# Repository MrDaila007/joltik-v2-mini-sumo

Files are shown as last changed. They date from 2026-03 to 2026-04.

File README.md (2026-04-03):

# Joltik V2 — Mini Sumo Robot



Mini sumo competition robot — from SolidWorks CAD to firmware for three hardware platforms. Includes Arduino sketches for ATmega328 (V1) and RP2040-Zero (V2), a Zephyr RTOS port, and a WiFi web-controller on ESP8266.

## Hardware

| | V1 Board | V2 Board |
|---|---|---|
| **MCU** | ATmega328 (Arduino Nano) | RP2040-Zero |
| **Opponent sensors** | 3x SharpIR analog + 2x digital | 4x digital (active-low) |
| **Edge sensors** | 1x analog | 2x analog |
| **Motor driver** | TA6586 dual H-bridge | TA6586 dual H-bridge |
| **Extras** | — | WS2812 LED, RC5 IR remote, servo, OLED (opt.) |
| **WiFi control** | — | ESP8266 (Wemos D1 Mini) companion |

## Repository Structure

```
CAD/
  ├── *.SLDASM / *.SLDPRT      SolidWorks assemblies & parts
  ├── CUT/                      DXF files for laser/CNC cutting
  ├── STEP/                     STEP exports for cross-CAD use
  └── STL/                      3D-printable models
FIRMWARE/
  ├── JoltikV1_last_test_firmware/   Competition firmware (ATmega328)
  ├── JoltikV2_sumo_firmware/        Competition firmware (RP2040-Zero)
  ├── JoltikV2_test_firmware/        Extended test with ESP telemetry link
  ├── Joltik_v2_sumo_board_test/     Hardware verification sketch (V2)
  ├── JoltikV2_web_controller/       WiFi dashboard (ESP8266)
  ├── joltik_v2_zephyr/              Zephyr RTOS firmware (RP2040-Zero)
  └── Lib/                           Vendored: NeoPixel, GyverMotor, RC5, SharpIR
.github/workflows/ci.yml            Arduino + Zephyr build CI
```

## Build & Upload

### Arduino (arduino-cli)

```bash
# V1 — Arduino Nano
arduino-cli compile --fqbn arduino:avr:nano --libraries FIRMWARE/Lib \
  FIRMWARE/JoltikV1_last_test_firmware/
arduino-cli upload  --fqbn arduino:avr:nano -p /dev/ttyUSB0 \
  FIRMWARE/JoltikV1_last_test_firmware/

# V2 — RP2040-Zero
arduino-cli compile --fqbn rp2040:rp2040:waveshare_rp2040_zero --libraries FIRMWARE/Lib \
  FIRMWARE/JoltikV2_sumo_firmware/
arduino-cli upload  --fqbn rp2040:rp2040:waveshare_rp2040_zero -p /dev/ttyACM0 \
  FIRMWARE/JoltikV2_sumo_firmware/

# Web controller — ESP8266 (Wemos D1 Mini)
arduino-cli compile --fqbn esp8266:esp8266:d1_mini --libraries FIRMWARE/Lib \
  FIRMWARE/JoltikV2_web_controller/
```

Libraries in `FIRMWARE/Lib/` must be accessible to the build system — pass `--libraries FIRMWARE/Lib` or copy/symlink into your Arduino libraries folder.

### Zephyr RTOS

```bash
cd FIRMWARE/joltik_v2_zephyr
west build -b rp2040_zero -p always
west flash          # or copy build/zephyr/zephyr.uf2 to the RP2040 in bootloader mode
```

## V2 Competition Firmware

- **State machine**: search (spin) -> attack (track & ram) -> backoff (on edge)
- **4 start tactics**: straight charge, reverse start, left sweep, right sweep
- **WS2812 LED status**: white = waiting, green = searching, blue = attacking, red = edge
- **Button**: single click = start/stop, double click = cycle tactics
- **IR remote** (RC5): tactic selection and start/stop (processed on RP2040 second core)
- **Servo**: pin 9, plow deployment
- **Optional OLED**: `#define USE_DISPLAY` — sensor states, tactic, IR commands
- **Serial debug**: `#define DEBUG_ENABLE` (115200 baud)

## Zephyr Firmware

Modular rewrite of the V2 competition firmware on Zephyr RTOS:

- Multi-threaded: IR decoding thread + main combat loop
- Persistent settings via NVS (flash storage)
- USB CDC-ACM console with shell commands for debug
- Zephyr logging subsystem
- Same state machine and tactics as the Arduino version

## Web Controller (ESP8266)

WiFi dashboard for the V2 robot via a companion Wemos D1 Mini:

- **AP**: SSID `Joltik-V2`, password `joltik2024`, accessible at `http://joltik.local`
- **WebSocket**: real-time sensor telemetry and motor control
- **Dashboard**: live robot visualization, motor sliders, D-pad, line sensor graphs, config panel, debug log
- **Serial link**: 9600 baud to RP2040-Zero (TX/RX on D5/D6)

## Pin Mapping (V2)

| Function | Pin |
|---|---|
| Motor A | GPIO 5, 6 |
| Motor B | GPIO 7, 8 |
| Opponent FL / FR | GPIO 12, 13 |
| Opponent L / R | GPIO 10, 11 |
| Line L / R | A3, A2 |
| Servo | GPIO 9 |
| Button | GPIO 15 |
| IR Receiver | GPIO 14 |
| WS2812 LED | GPIO 16 |
| OLED SDA / SCL | GPIO 2, 3 |

## License

[Apache 2.0](LICENSE) — 2026 Danila Surok

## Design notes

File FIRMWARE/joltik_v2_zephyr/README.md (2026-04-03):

# Joltik V2 Zephyr Firmware

Zephyr RTOS firmware for the Joltik V2 mini sumo robot on RP2040-Zero.

Modular rewrite of the Arduino competition firmware with multi-threading, persistent settings (NVS), interactive shell over USB, and a full unit test suite.

## Quick Start

```bash
# Build
make

# Flash (hold BOOTSEL, plug USB, release)
make flash

# Serial console (shell + logs)
make monitor

# Build with OLED display support
make display
```

## Features

- **Combat state machine** — search / attack / backoff with 4 configurable start tactics
- **4 opponent sensors** (IR, active-low) + **2 line sensors** (ADC)
- **WS2812 LED** — color-coded robot state
- **RC5 IR remote** — tactic selection and start/stop (dedicated thread)
- **Servo** — plow deployment (0-180 degrees)
- **Button** — single click start/stop, double click cycle tactics
- **Persistent settings** — speeds, tactic, line threshold saved to flash (NVS)
- **USB shell** — live sensor readout, motor test, config tuning (115200 baud)
- **Optional OLED** — SSD1306 128x32 via I2C (`CONFIG_JOLTIK_DISPLAY=y`)
- **Unit tests** — 7 test suites on native_sim

## Build Requirements

- Zephyr SDK 0.17+ with ARM toolchain
- West workspace with Zephyr v4.3
- Python venv with west, pyelftools

Paths are configured in `Makefile` — adjust `ZEPHYR_BASE`, `ZEPHYR_SDK`, and `VENV` to match your setup.

## Make Targets

| Target | Description |
|---|---|
| `make` / `make build` | Build firmware |
| `make flash` | Copy UF2 to RP2040 in bootloader mode |
| `make monitor` | Open USB serial console |
| `make flash-monitor` | Flash then monitor |
| `make display` | Build with OLED enabled |
| `make test` | Build and run unit tests |
| `make size` | Show firmware size |
| `make rom_report` / `make ram_report` | Memory usage |
| `make menuconfig` | Interactive Kconfig |
| `make clean` / `make pristine` | Clean build |

## Project Structure

```
├── CMakeLists.txt
├── Kconfig                     # Optional features (display, IR)
├── prj.conf                    # Zephyr kernel config
├── Makefile                    # Build shortcuts
├── boards/
│   └── rp2040_zero.overlay     # Pin mappings (devicetree)
├── src/
│   ├── main.c                  # State machine & main loop
│   ├── motors.c/h              # PWM motor control
│   ├── sensors.c/h             # Opponent (GPIO) + line (ADC) sensors
│   ├── combat.c/h              # Attack / backoff / search logic
│   ├── tactics.c/h             # 4 start routines
│   ├── led.c/h                 # WS2812 state colors
│   ├── servo.c/h               # Servo angle control
│   ├── button.c/h              # Debounced single/double click
│   ├── rc5.c/h                 # RC5 IR protocol decoder
│   ├── settings.c/h            # NVS persistent storage
│   ├── shell_cmds.c            # Shell command handlers
│   └── display.c/h             # Optional SSD1306 OLED
└── tests/                      # ztest unit tests (native_sim)
```

## Documentation

- [Architecture](docs/architecture.md) — modules, threads, state machine
- [Pin Mapping](docs/pinout.md) — GPIO, PWM, ADC assignments
- [Shell Commands](docs/shell.md) — interactive debug interface
- [Settings](docs/settings.md) — persistent configuration via NVS
- [Testing](docs/testing.md) — unit tests and how to run them

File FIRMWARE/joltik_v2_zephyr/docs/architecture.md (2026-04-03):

# Architecture

## Modules

```
main.c ─────── State machine, init, main loop
  ├── motors     PWM drive control (-255..255)
  ├── sensors    4x opponent GPIO + 2x line ADC
  ├── combat     attack() / backoff() / search()
  ├── tactics    4 start routines
  ├── led        WS2812 color by state
  ├── servo      Plow angle (0-180)
  ├── button     Single/double click detection
  ├── rc5        RC5 IR decoder (separate thread)
  ├── settings   NVS flash persistence
  ├── shell_cmds Debug commands over USB
  └── display    Optional SSD1306 OLED
```

## Threads

| Thread | Stack | Priority | Role |
|---|---|---|---|
| **main** | 4096 B | 0 (preemptive) | State machine, combat loop |
| **ir_thread** | 1024 B | 5 (cooperative) | RC5 message dispatch (tactic select / power toggle) |
| **system workqueue** | 2048 B | — | Deferred LED updates, display refresh |

## State Machine

```
                 ┌──────────┐
        power on │ WAITING  │ LED: white
                 │ (idle)   │ Button/IR/start_pin triggers start
                 └────┬─────┘
                      │ start event
                 ┌────▼─────┐
                 │COUNTDOWN │ LED: green, 5 sec (1s per count)
                 └────┬─────┘
                      │
                 ┌────▼─────┐
                 │ TACTIC   │ LED: yellow, executes selected tactic (0-3)
                 └────┬─────┘
                      │
              ┌───────▼────────┐
              │  COMBAT LOOP   │
              │                │
              │  ┌──────────┐  │
          no  │  │ SEARCH   │  │ LED: green
       opponent  │ (spin)   │  │ Rotate in searchDir
              │  └─────┬────┘  │
              │   opponent     │
              │   detected     │
              │  ┌─────▼────┐  │
              │  │ ATTACK   │  │ LED: blue
              │  │ (track)  │  │ Priority-based targeting
              │  └─────┬────┘  │
              │   edge         │
              │   detected     │
              │  ┌─────▼────┐  │
              │  │ BACKOFF  │  │ LED: red
              │  │ (escape) │  │ Reverse → rotate → forward
              │  └──────────┘  │
              └───────┬────────┘
                      │ button press
                 ┌────▼─────┐
                 │ WAITING  │ motors stop
                 └──────────┘
```

## Attack Priority

When opponent is detected, `attack()` checks sensors in this order:

1. **All 4 sensors** — full ram at `max_speed` + ramp counter (accelerating)
2. **Both front** (FL + FR) — straight at `attack_speed`
3. **Front-left** — slight left turn
4. **Front-right** — slight right turn
5. **Side-left only** — tank rotate left (200ms timeout)
6. **Side-right only** — tank rotate right (200ms timeout)

## Start Tactics

| ID | Name | Behavior |
|---|---|---|
| 0 | Straight charge | Forward 150ms, then search for 200ms |
| 1 | Reverse start | Reverse 400ms, rotate 150ms, then tactic 0 |
| 2 | Left sweep | Rotate left 300ms, then tactic 0 |
| 3 | Right sweep | Rotate right 300ms, then tactic 0 |

## Edge Detection

Line sensors (ADC) are checked every loop iteration:
- `line_read_left()` / `line_read_right()` return 12-bit ADC values (0-4095)
- Value **above** threshold = on ring (black surface)
- Value **at or below** threshold = ring edge (white line)
- Left edge detected → `backoff(DIR_RIGHT)`
- Right edge detected → `backoff(DIR_LEFT)`
- Default threshold: **2000** (configurable via shell or NVS)

## Motor Control

`drive(left, right)` accepts values from -255 to 255:
- Positive = forward, negative = reverse
- Direction pin set to 0 (forward) or 1 (reverse)
- PWM duty: `pulse = period * abs(speed) / 255`
- Both motors share 50Hz PWM (20ms period)

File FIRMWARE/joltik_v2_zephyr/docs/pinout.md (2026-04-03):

# Pin Mapping

RP2040-Zero pinout for the Joltik V2 sumo board. Defined in `boards/rp2040_zero.overlay`.

## GPIO Assignment

| Function | GPIO | Type | Notes |
|---|---|---|---|
| Motor L speed | 5 | PWM (slice 2B) | 50 Hz, duty 0-100% |
| Motor L direction | 6 | Output | 0 = forward, 1 = reverse |
| Motor R direction | 7 | Output | 0 = forward, 1 = reverse |
| Motor R speed | 8 | PWM (slice 4A) | 50 Hz, duty 0-100% |
| Servo | 9 | PWM (slice 4B) | 50 Hz, 500-2500 us pulse |
| Opponent side-left | 10 | Input, active-low | IR distance sensor |
| Opponent side-right | 11 | Input, active-low | IR distance sensor |
| Opponent front-left | 12 | Input, active-low | IR distance sensor |
| Opponent front-right | 13 | Input, active-low | IR distance sensor |
| IR receiver | 14 | Input, active-low | RC5 protocol |
| Button | 15 | Input, active-high | 50ms debounce |
| WS2812 LED | 16 | LED strip (PIO) | Single RGB pixel |
| Line sensor right | 28 (A2) | ADC channel 2 | 12-bit, 0-4095 |
| Line sensor left | 29 (A3) | ADC channel 3 | 12-bit, 0-4095 |

## PWM Notes

- GPIO 8 (motor R) and GPIO 9 (servo) share **PWM slice 4** — both run at 50 Hz
- GPIO 5 (motor L) uses **PWM slice 2**
- Motor PWM period: 20 ms (50 Hz)
- Servo pulse: 500 us (0 deg) to 2500 us (180 deg)

## USB

- CDC ACM UART on USB for shell console and logging (115200 baud)

## Flash Layout

| Region | Offset | Size | Purpose |
|---|---|---|---|
| Code | 0x100 | ~1984 KB | Application firmware |
| NVS storage | 0x1F0000 | 64 KB | Persistent settings |

## I2C (optional OLED)

Enabled with `CONFIG_JOLTIK_DISPLAY=y`:

| Function | GPIO |
|---|---|
| SDA | 2 |
| SCL | 3 |

Display: SSD1306 128x32, I2C address 0x3C.

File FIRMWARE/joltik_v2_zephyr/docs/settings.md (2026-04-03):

# Settings

Robot parameters are stored in flash via Zephyr NVS (Non-Volatile Storage) and persist across power cycles.

## Parameters

| Parameter | Default | Range | Description |
|---|---|---|---|
| `current_tactic` | 0 | 0-3 | Start tactic (straight / reverse / left / right) |
| `line_threshold` | 2000 | 0-4095 | ADC threshold for ring edge detection |
| `max_speed` | 200 | 0-255 | Ram speed when all sensors triggered |
| `straight_speed` | 125 | 0-255 | Forward speed after tactic |
| `search_speed` | 100 | 0-255 | Rotation speed while searching |
| `rotate_speed` | 125 | 0-255 | Rotation speed during attack tracking |
| `breakout_speed` | 160 | 0-255 | Reverse/escape speed on edge |
| `attack_speed` | 125 | 0-255 | Forward speed when opponent in front |

## NVS Keys

Settings are stored under the `joltik` namespace:

| Key | Type | Mapped to |
|---|---|---|
| `joltik/tactic` | uint8 | `current_tactic` |
| `joltik/threshold` | uint16 | `line_threshold` |
| `joltik/max_spd` | uint8 | `max_speed` |
| `joltik/str_spd` | uint8 | `straight_speed` |
| `joltik/srch_spd` | uint8 | `search_speed` |
| `joltik/rot_spd` | uint8 | `rotate_speed` |
| `joltik/brk_spd` | uint8 | `breakout_speed` |
| `joltik/atk_spd` | uint8 | `attack_speed` |

## Usage

### Via Shell

```
config show                    # view all
config threshold 1800          # change threshold
config speed max 220           # change max speed
config save                    # write to flash
```

Changes take effect immediately but are **not saved to flash** until `config save` is called.

### Via Code

```c
#include "settings.h"

// Global instance
extern struct robot_settings g_settings;

// Read
uint8_t spd = g_settings.max_speed;

// Modify
g_settings.max_speed = 220;

// Persist to flash
app_settings_save();
```

### Startup Flow

1. `app_settings_init()` called from `main()`
2. NVS subsystem initialized (`settings_subsys_init`)
3. Settings loaded from flash (`settings_load`)
4. Missing keys filled with defaults
5. `g_settings` ready for use

## Flash Storage

- Partition: 64 KB at offset `0x1F0000`
- Backend: Zephyr NVS
- Wear leveling handled by NVS internally
- Write protection disabled via `CONFIG_MPU_ALLOW_FLASH_WRITE=y`

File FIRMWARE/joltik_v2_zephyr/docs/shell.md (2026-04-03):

# Shell Commands

Interactive debug shell over USB CDC ACM (115200 baud). Connect with any serial terminal:

```bash
make monitor
# or
picocom /dev/ttyACM0 -b 115200
```

## Commands

### sensors

Read all sensor values.

```
uart:~$ sensors
Opponent: FL=1 FR=0 L=0 R=0
Line:     L=2850 R=3100  ring: L=yes R=yes
```

### motor drive / motor stop

Direct motor control for testing.

```
uart:~$ motor drive 100 100     # both forward at ~40% speed
uart:~$ motor drive -150 150    # tank rotate left
uart:~$ motor drive 0 0         # stop
uart:~$ motor stop              # same as drive 0 0
```

Values: -255 to 255 (clamped).

### tactic

Get or set the current start tactic.

```
uart:~$ tactic             # show current
Current tactic: 0
uart:~$ tactic 2           # set to left sweep
Tactic set to 2
```

Tactics: 0 = straight, 1 = reverse, 2 = left sweep, 3 = right sweep.

### config show

Display all settings.

```
uart:~$ config show
  tactic:    0
  threshold: 2000
  max_speed: 200
  straight:  125
  search:    100
  rotate:    125
  breakout:  160
  attack:    125
```

### config threshold

Set line sensor threshold (0-4095).

```
uart:~$ config threshold 1800
Line threshold set to 1800
```

Higher value = more sensitive to ring edge.

### config speed

Adjust motor speed parameters.

```
uart:~$ config speed max 220
uart:~$ config speed search 80
uart:~$ config speed attack 150
```

Valid names: `max`, `straight`, `search`, `rotate`, `breakout`, `attack`.
Valid values: 0-255.

### config save

Persist current settings to flash. They survive power cycles.

```
uart:~$ config save
Settings saved
```

### led

Set LED to a specific RGB color (for testing).

```
uart:~$ led 255 0 0        # red
uart:~$ led 0 255 0        # green
uart:~$ led 0 0 0          # off
```

### servo

Set servo angle (for testing).

```
uart:~$ servo 0             # fully retracted
uart:~$ servo 90            # center
uart:~$ servo 180           # fully extended
```

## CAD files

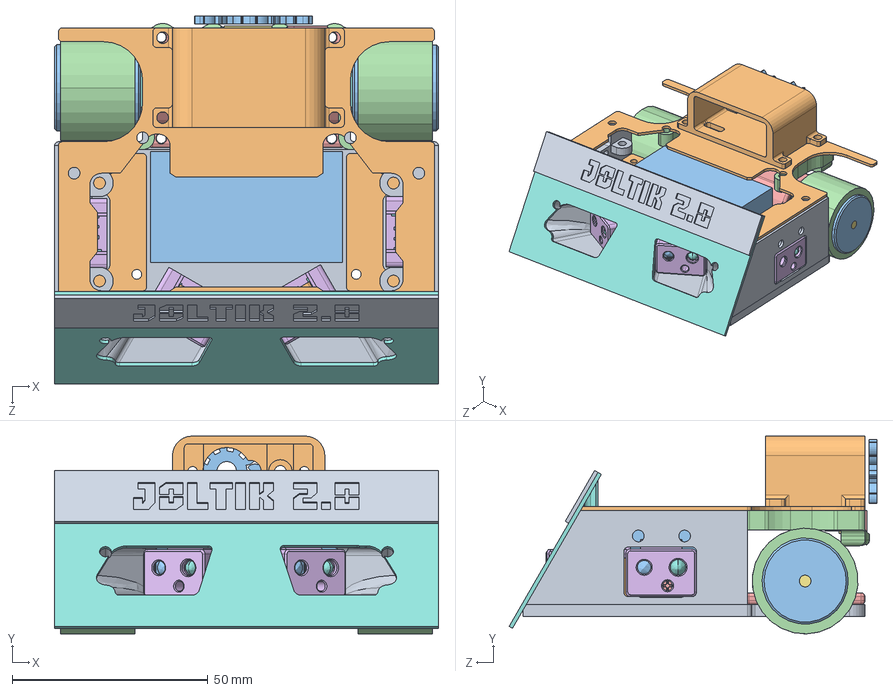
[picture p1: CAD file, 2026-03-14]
CAD/STEP/Joltik2.0 Assembly.STEP
98.0 x 50.5 x 93.8 mm
Base plate_По умолчанию
верхняя пластина_По умолчанию
Sumo_weel x 2
Tire_new_По умолчанию x 2
Motor bracket_По умолчанию x 2
Motor_По умолчанию x 2
Main_1_По умолчанию
Board.STEP x 4
1608.STEP x 40
LED-1608.STEP x 8
LED-5MM.STEP x 4
SOT-23.STEP x 4
SOIC-08N.STEP x 4
TSSP40_Right angle bend.STEP x 4
2012.STEP x 4
SMD-RS-VR.STEP x 4
MO Casing.STEP x 4
pololu-QTR-1a x 2
Front plate_По умолчанию
Side panel_По умолчанию x 2
weight boost_По умолчанию x 2
Battery
Charger_port_По умолчанию
XT30U-M
JST - XH - Thru (V) - 4Pin - 2.54mm
Part2^Joltik2.0 Assembly
Joltik_logo
Servo mount_По умолчанию
spur gear_iso_ISO - Spur gear 1.375M 10T 20PA 2FW ---S10A75H50L5.0N x 2

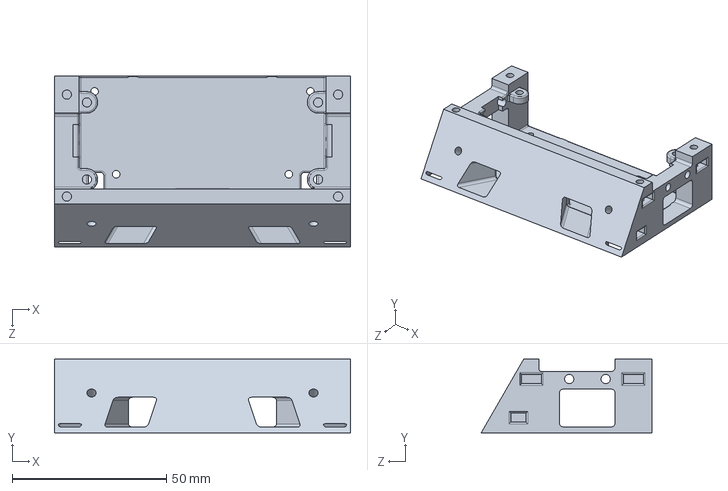
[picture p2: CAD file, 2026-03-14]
CAD/Main.SLDPRT
96.0 x 24.0 x 55.4 mm

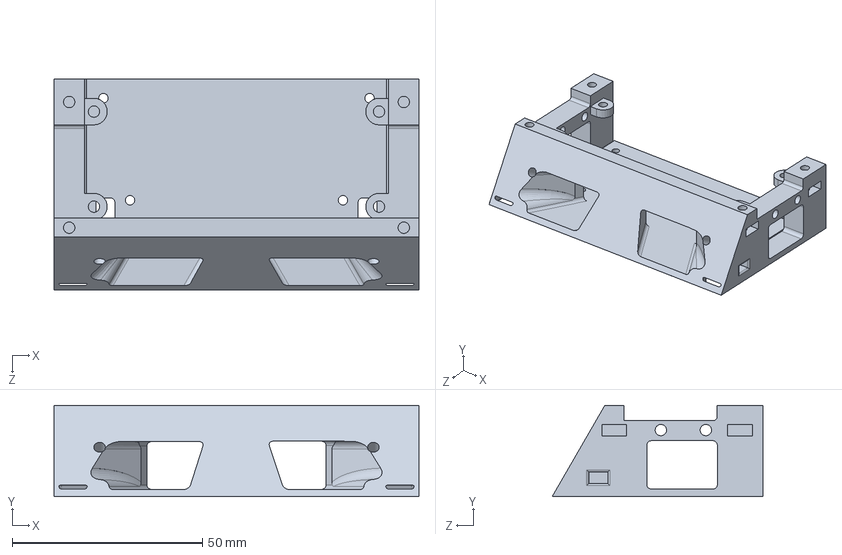
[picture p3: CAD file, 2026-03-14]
CAD/Main_1.SLDPRT
96.0 x 24.0 x 55.4 mm

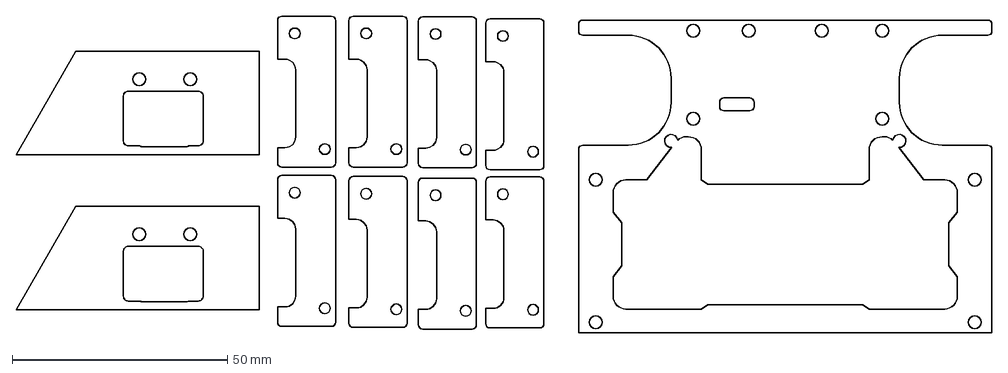
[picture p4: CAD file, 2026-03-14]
CAD/CUT/Side_weight_boost_top_panel_1mm.DXF
226.6 x 73.5 mm

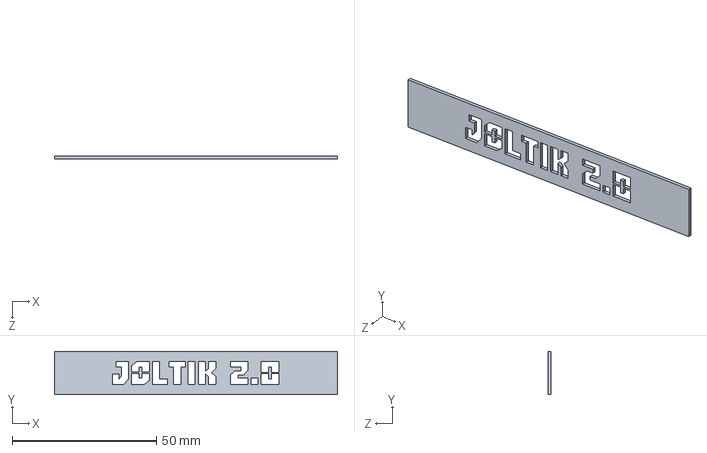
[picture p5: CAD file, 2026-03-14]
CAD/Joltik_logo.SLDPRT
98.0 x 15.0 x 1.00 mm

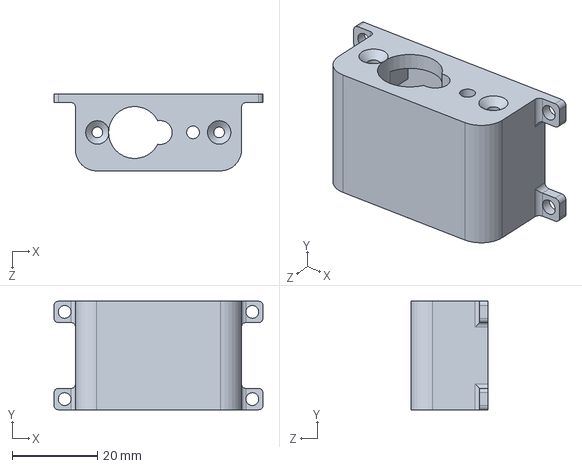
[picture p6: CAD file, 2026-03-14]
CAD/STL/Servo mount.SLDPRT
48.9 x 25.4 x 18.0 mm

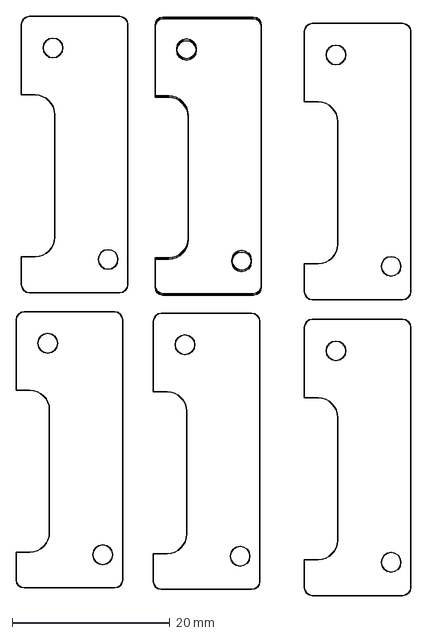
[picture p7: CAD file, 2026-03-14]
CAD/CUT/weight boostz_2mm.DXF
50.1 x 73.5 mm

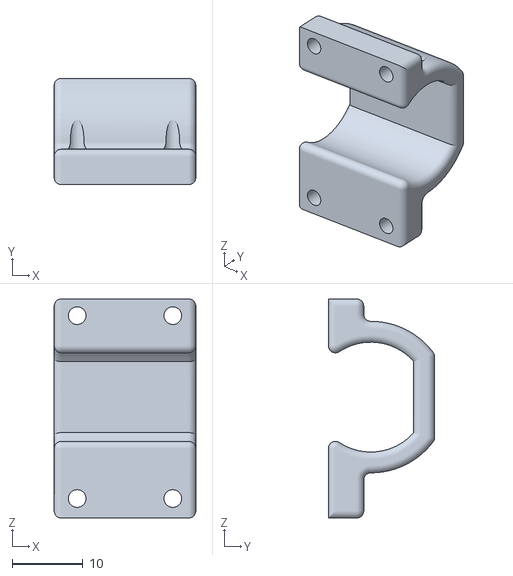
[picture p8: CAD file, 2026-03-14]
CAD/STL/Motor bracket_offset.STL
20.0 x 15.0 x 30.9

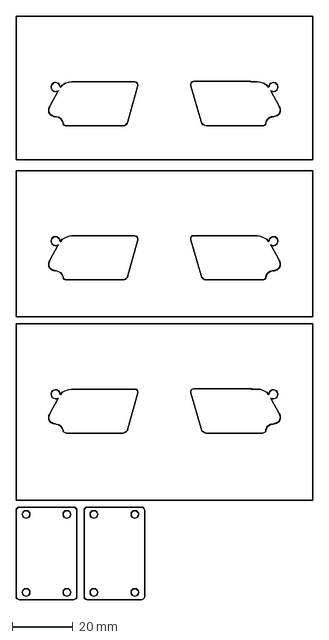
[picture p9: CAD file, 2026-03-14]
CAD/CUT/Front_plate_9-20mm_motor_spacer_1mm.DXF
98.0 x 192.8 mm

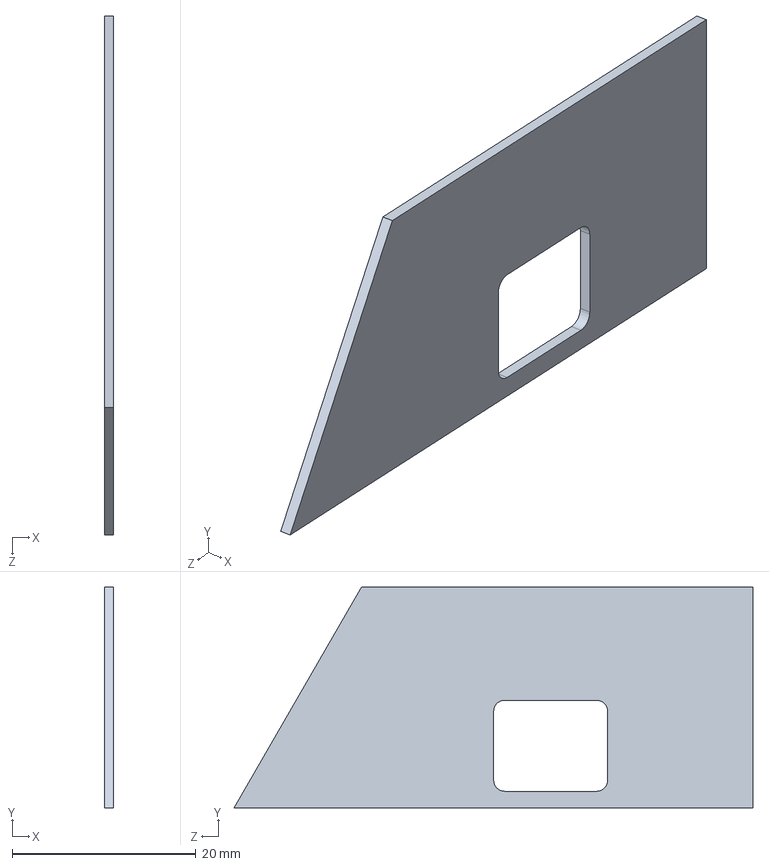
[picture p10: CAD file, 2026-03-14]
CAD/Side panel.SLDPRT
1.00 x 24.0 x 56.4 mm

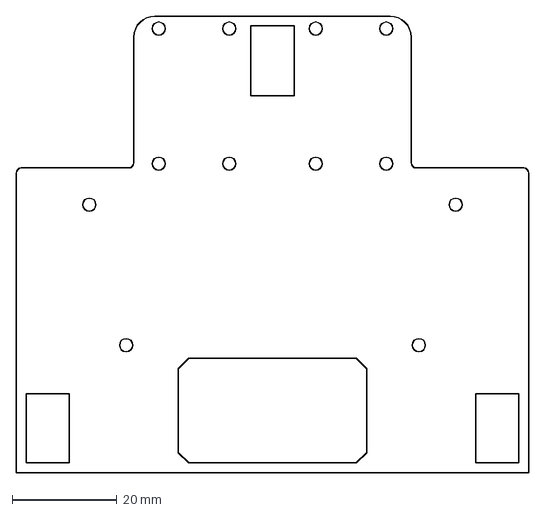
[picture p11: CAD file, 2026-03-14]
CAD/CUT/Base plate_3mm.DXF
98.0 x 87.3 mm

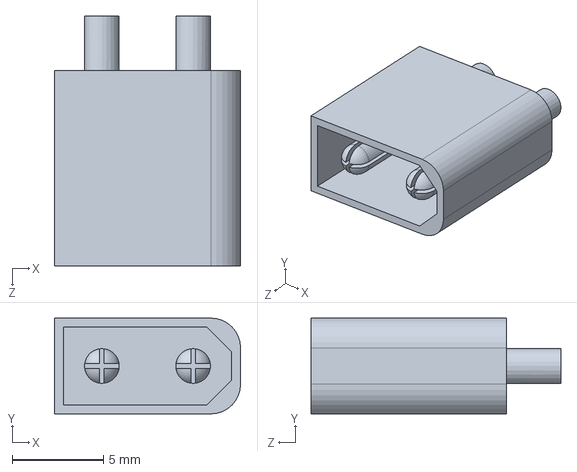
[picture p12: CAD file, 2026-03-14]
CAD/XT30U-M.SLDPRT
10.2 x 5.25 x 13.7 mm

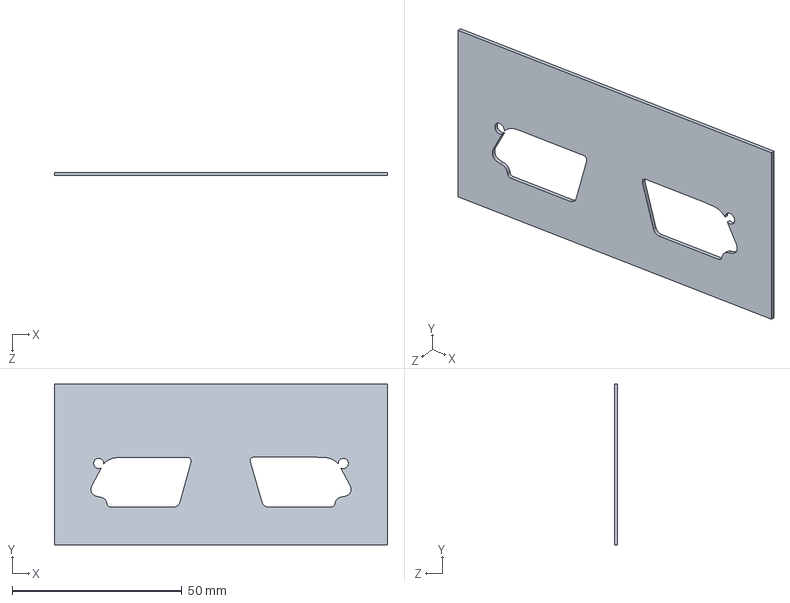
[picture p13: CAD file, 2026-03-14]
CAD/Front plate_9mm.SLDPRT
98.0 x 47.4 x 1.00 mm

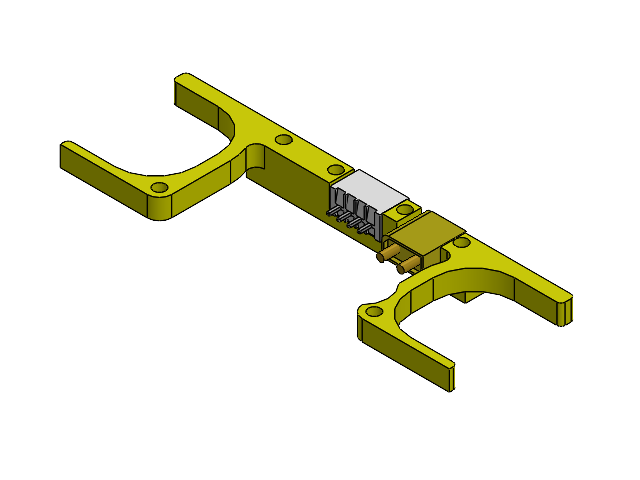
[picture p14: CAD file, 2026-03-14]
CAD/Assem_Power_port.SLDASM
Charger_port
XT30U-M
JST - XH - Thru (V) - 4Pin - 2.54mm

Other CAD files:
CAD/Servo.SLDASM
CAD/Joltik2.0 Assembly Base+sensors.SLDASM
CAD/MAKER-OBJECT.SLDASM
CAD/Motor bracket_offsrt.SLDPRT
CAD/Base plate.SLDPRT
CAD/Battery.SLDPRT
CAD/CUT/Base plate_3mm.SLDDRW
CAD/CUT/Front_plate_9-20mm_motor_spacer_1mm.SLDDRW
CAD/CUT/Side_weight_boost_top_panel_1mm.SLDDRW
CAD/CUT/weight boostz_2mm.SLDDRW
CAD/Charger_port.SLDPRT
CAD/Front plate.SLDPRT
CAD/Front plate_10mm.SLDPRT
CAD/Front plate_20mm.SLDPRT
CAD/JS7444_wheel.SLDPRT
CAD/JST - XH - Thru (V) - 4Pin - 2.54mm.SLDPRT
CAD/Joltik2.0 Assembly.SLDASM
CAD/Motor bracket.SLDPRT
CAD/Motor.SLDPRT
CAD/Motor_spacer.SLDPRT
CAD/STL/Charger_port.STL
CAD/STL/Joltik_logo.STL
CAD/STL/Main.STL
CAD/STL/Motor bracket.STL
CAD/STL/Motor_spacer.STL
CAD/STL/Servo mount.STL
CAD/STL/Servo_gear_1.STL
CAD/STL/Servo_gear_2.STL
CAD/Servo mount.SLDPRT
CAD/Servo_gear_1.SLDPRT
CAD/Servo_gear_2.SLDPRT
CAD/Servo_gear_2.STL
CAD/Sumo_weel.SLDPRT
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

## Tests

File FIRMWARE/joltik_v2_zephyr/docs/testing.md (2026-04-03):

# Testing

Unit tests run on `native_sim` (Zephyr's hardware emulation) using the ztest framework. No physical hardware needed.

## Running Tests

```bash
make test
```

This builds and executes all test suites. Expected output:

```
START - test_rc5
 PASS - test_rc5_reset
 PASS - test_rc5_invalid_timing
 ...
START - test_motors
 PASS - test_drive_forward
 PASS - test_drive_reverse
 ...
PROJECT EXECUTION SUCCESSFUL
```

## Test Suites

| Suite | File | What it tests |
|---|---|---|
| **test_rc5** | `test_rc5.c` | RC5 decoder state machine: reset, timing validation, short/long pulses, full frame decode |
| **test_motors** | `test_motors.c` | Motor PWM: forward, reverse, turns, stop, value clamping |
| **test_sensors** | `test_sensors.c` | Opponent GPIO read (all 4 + combined), line ADC read, threshold logic |
| **test_servo** | `test_servo.c` | Servo angle: init, 0/90/180 degrees, clamping, sweep |
| **test_settings** | `test_settings.c` | NVS persistence: default values, save/reload cycle, all speed fields |
| **test_combat** | `test_combat.c` | Combat logic: search direction, attack priorities, edge backoff |
| **test_led** | `test_led.c` | LED state-to-color mapping, custom color, update counting |

## Hardware Emulation

Tests use Zephyr emulation drivers defined in `tests/boards/native_sim.overlay`:

- **gpio_emul** — 30-pin virtual GPIO (opponent sensors, motor direction, button)
- **fake-pwm** — Virtual PWM (motor speed, servo)
- **adc_emul** — Virtual ADC with injectable values (line sensors)
- **fake_led_strip.c** — Custom LED driver that stores pixel data and counts updates

Tests inject sensor values via `gpio_emul_input_set()` and `adc_emul_const_value_set()`, then verify motor output via `gpio_emul_output_get()`.

## Adding Tests

1. Create `tests/src/test_<module>.c`
2. Use `ZTEST_SUITE()` and `ZTEST()` macros
3. Add source to `tests/CMakeLists.txt`
4. Run `make test`

Example:

```c
#include <zephyr/ztest.h>

ZTEST_SUITE(test_mymodule, NULL, NULL, NULL, NULL, NULL);

ZTEST(test_mymodule, test_something)
{
    zassert_equal(1 + 1, 2);
}
```

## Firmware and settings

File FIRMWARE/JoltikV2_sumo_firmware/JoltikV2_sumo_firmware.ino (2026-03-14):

// Joltik V2 - Mini Sumo Competition Firmware
// RP2040-Zero based board with TA6586 motor driver
// 4x digital opponent sensors, 2x analog line sensors
// WS2812 RGB LED, RC5 IR remote, servo, optional OLED

#include <RC5.h>
#include "GyverButton.h"
#include <Adafruit_NeoPixel.h>
#include <Servo.h>
#include <Wire.h>

// Uncomment to enable OLED display (I2C 0.91" 128x32 SSD1306, SDA=GPIO2, SCL=GPIO3)
//#define USE_DISPLAY

// Uncomment to enable serial debug output
//#define DEBUG_ENABLE

#ifdef USE_DISPLAY
  #include <GyverOLED.h>
  GyverOLED<SSD1306_128x32, OLED_BUFFER> oled;
#endif

// ==================== Pin Definitions ====================
// Motor Driver (TA6586 2-wire)
#define AIN_1 5
#define AIN_2 6
#define BIN_1 7
#define BIN_2 8

// Opponent Sensors (digital, active-low)
#define SEN_FR 13   // Front right
#define SEN_FL 12   // Front left
#define SEN_R  11   // Side right
#define SEN_L  10   // Side left

// Line / Edge Sensors (analog)
#define SEN_Line_R A2
#define SEN_Line_L A3

// Peripherals
#define SERVO_PIN 9
#define BTN_PIN   15
#define IR_PIN    14
#define RGB_LED   16  // WS2812 x1

// ==================== Speed Constants ====================
#define MAX_SPEED          200
#define STRAIGHT_SPEED     125
#define SEARCH_SPEED       100
#define ROTATE_TANK_SPEED  125
#define ROTATE_SPEED       125
#define BREAKOUT_SPEED     160
#define ATTACK_SPEED       125

// ==================== Direction ====================
#define LEFT  0
#define RIGHT 1

// ==================== Objects ====================
Adafruit_NeoPixel pixels(1, RGB_LED, NEO_GRB + NEO_KHZ800);
RC5 rc5(IR_PIN);
GButton butt1(BTN_PIN);
Servo plow;

// ==================== Colors ====================
#define COLOR_OFF     pixels.Color(0, 0, 0)
#define COLOR_WHITE   pixels.Color(255, 255, 255)
#define COLOR_RED     pixels.Color(255, 0, 0)
#define COLOR_GREEN   pixels.Color(0, 255, 0)
#define COLOR_BLUE    pixels.Color(0, 0, 255)
#define COLOR_YELLOW  pixels.Color(255, 255, 0)
#define COLOR_ORANGE  pixels.Color(255, 80, 0)

// ==================== Global State ====================
uint8_t searchDir = LEFT;
int count = 0;
bool running = false;
uint8_t currentTactic = 0;
const uint8_t TACTIC_COUNT = 4;
String lastIRCommand = "None";

// Line sensor threshold (above = on ring, below = edge/white)
#define LINE_THRESHOLD 500

// ==================== Sensor Functions ====================
// All opponent sensors are active-low: LOW = opponent detected

bool statusFR() {
  return !digitalRead(SEN_FR);
}

bool statusFL() {
  return !digitalRead(SEN_FL);
}

bool statusR() {
  return !digitalRead(SEN_R);
}

bool statusL() {
  return !digitalRead(SEN_L);
}

// "Front" = both front sensors see opponent
bool statusFront() {
  return statusFL() && statusFR();
}

// Any opponent sensor triggered
bool opponentDetected() {
  return statusFL() || statusFR() || statusL() || statusR();
}

// Line sensors: return true if on ring (dark surface, high reading)
bool lineSensL() {
  return analogRead(SEN_Line_L) > LINE_THRESHOLD;
}

bool lineSensR() {
  return analogRead(SEN_Line_R) > LINE_THRESHOLD;
}

// ==================== Motor Control ====================
void drive(int left, int right) {
  left = constrain(left, -255, 255);
  right = constrain(right, -255, 255);

  if (left >= 0) {
    digitalWrite(AIN_2, LOW);
    analogWrite(AIN_1, abs(left));
  } else {
    digitalWrite(AIN_2, HIGH);
    analogWrite(AIN_1, abs(left));
  }

  if (right >= 0) {
    digitalWrite(BIN_1, LOW);
    analogWrite(BIN_2, abs(right));
  } else {
    digitalWrite(BIN_1, HIGH);
    analogWrite(BIN_2, abs(right));
  }
}

// ==================== LED Helpers ====================
void setLED(uint32_t color) {
  pixels.setPixelColor(0, color);
  pixels.show();
}

// ==================== Start Routine ====================
void startRoutine() {
  setLED(COLOR_GREEN);

  // Initial charge forward
  drive(STRAIGHT_SPEED, STRAIGHT_SPEED);
  delay(150);

  drive(0, 0);
  delay(50);

  // Briefly search for opponent
  uint32_t startTimestamp = millis();
  while (!statusFront()) {
    if (millis() - startTimestamp > 200) {
      break;
    }
  }
}

// ==================== Back Off ====================
void backoff(uint8_t dir) {
  setLED(COLOR_RED);

  // Reverse
  drive(-BREAKOUT_SPEED, -BREAKOUT_SPEED);
#ifdef DEBUG_ENABLE
  Serial.println("Reverse");
#endif
  delay(200);

  // Stop briefly
  drive(0, 0);
  delay(50);

  // Rotate away from edge
  if (dir == LEFT) {
    drive(-ROTATE_SPEED, ROTATE_SPEED);
#ifdef DEBUG_ENABLE
    Serial.println("Dir_Left");
#endif
  } else {
    drive(ROTATE_SPEED, -ROTATE_SPEED);
#ifdef DEBUG_ENABLE
    Serial.println("Dir_Right");
#endif
  }
  delay(100);

  // Look for opponent during rotation
  uint32_t uTurnTimestamp = millis();
  while (millis() - uTurnTimestamp < 200) {
    if (opponentDetected()) {
      drive(0, 0);
      delay(50);
#ifdef DEBUG_ENABLE
      Serial.println("Backoff Trig");
#endif
      return;
    }
  }

  // If no opponent found, move forward
  drive(STRAIGHT_SPEED, STRAIGHT_SPEED);
  delay(100);
}

// ==================== Search ====================
void search() {
  setLED(COLOR_GREEN);

  if (searchDir == LEFT) {
    drive(-SEARCH_SPEED, SEARCH_SPEED);
#ifdef DEBUG_ENABLE
    Serial.println("Search_Left");
#endif
  } else {
    drive(SEARCH_SPEED, -SEARCH_SPEED);
#ifdef DEBUG_ENABLE
    Serial.println("Search_Right");
#endif
  }
}

// ==================== Attack ====================
void attack() {
  setLED(COLOR_BLUE);
  uint32_t attackTimestamp = millis();

  // Check line sensors first
  bool lineL = lineSensL();
  bool lineR = lineSensR();

  if (!lineL && !lineR) {
    // Both edges detected - back off right
    backoff(RIGHT);
    return;
  }
  if (!lineL) {
    // Left edge detected - back off right (turn away from left edge)
    backoff(RIGHT);
    return;
  }
  if (!lineR) {
    // Right edge detected - back off left (turn away from right edge)
    backoff(LEFT);
    return;
  }

  // Priority 1: All four sensors - full speed ram
  if (statusFront() && statusL() && statusR()) {
    drive(MAX_SPEED + count, MAX_SPEED + count);
    count++;
#ifdef DEBUG_ENABLE
    Serial.println("Attack ALL Max Speed");
#endif
  }
  // Priority 2: Both front sensors - straight attack
  else if (statusFront()) {
    drive(ATTACK_SPEED, ATTACK_SPEED);
#ifdef DEBUG_ENABLE
    Serial.println("Attack Front");
#endif
  }
  // Priority 3: Front-left only - slight left turn
  else if (statusFL()) {
    searchDir = LEFT;
    drive(ATTACK_SPEED - 30, ATTACK_SPEED + 10);
#ifdef DEBUG_ENABLE
    Serial.println("Attack Front-Left");
#endif
  }
  // Priority 4: Front-right only - slight right turn
  else if (statusFR()) {
    searchDir = RIGHT;
    drive(ATTACK_SPEED + 10, ATTACK_SPEED - 30);
#ifdef DEBUG_ENABLE
    Serial.println("Attack Front-Right");
#endif
  }
  // Priority 5: Side-left only - rotate left
  else if (statusL()) {
    searchDir = LEFT;
    drive(-ROTATE_SPEED, ROTATE_SPEED);
#ifdef DEBUG_ENABLE
    Serial.println("Attack Side-Left");
#endif
    while (!statusFront()) {
      if (millis() - attackTimestamp > 200) break;
    }
  }
  // Priority 6: Side-right only - rotate right
  else if (statusR()) {
    searchDir = RIGHT;
    drive(ROTATE_SPEED, -ROTATE_SPEED);
#ifdef DEBUG_ENABLE
    Serial.println("Attack Side-Right");
#endif
    while (!statusFront()) {
      if (millis() - attackTimestamp > 200) break;
    }
  }
}

// ==================== Tactics ====================
void tactics(uint8_t mode) {
  // Placeholder for different starting strategies
  switch (mode) {
    case 0: // Default: straight charge
      startRoutine();
      break;
    case 1: // Reverse start
      drive(-MAX_SPEED + 10, -MAX_SPEED);
      delay(400);
      drive(-ROTATE_TANK_SPEED, ROTATE_TANK_SPEED);
      delay(150);
      drive(0, 0);
      delay(50);
      startRoutine();
      break;
    case 2: // Left sweep
      drive(-SEARCH_SPEED, SEARCH_SPEED);
      delay(300);
      startRoutine();
      break;
    case 3: // Right sweep
      drive(SEARCH_SPEED, -SEARCH_SPEED);
      delay(300);
      startRoutine();
      break;
  }
}

// ==================== Stop (blink LED) ====================
void stopRobot() {
  running = false;
  drive(0, 0);
  count = 0;
#ifdef DEBUG_ENABLE
  Serial.println("STOPPED");
#endif

  // Blink white/off to indicate stopped state
  while (!running) {
    butt1.tick();
    if (butt1.isSingle()) {
      running = true;
      return;
    }
    if (butt1.isDouble()) {
      currentTactic = (currentTactic + 1) % TACTIC_COUNT;
#ifdef DEBUG_ENABLE
      Serial.print("Tactic: ");
      Serial.println(currentTactic);
#endif
      // Flash tactic number
      for (uint8_t i = 0; i <= currentTactic; i++) {
        setLED(COLOR_YELLOW);
        delay(150);
        setLED(COLOR_OFF);
        delay(150);
      }
    }

    setLED(COLOR_WHITE);
    delay(500);
    setLED(COLOR_OFF);
    delay(500);
  }
}

// ==================== IR Remote (Core 1) ====================
void loop1() {
  processIR();
}

void processIR() {
  unsigned char toggle, address, command;
  if (rc5.read(&toggle, &address, &command)) {
    lastIRCommand = "A:" + String(address) + " C:" + String(command);
#ifdef DEBUG_ENABLE
    Serial.println("IR: " + lastIRCommand);
#endif

    // Map IR commands
    switch (command) {
      case 1: // Tactic 0
      case 2: // Tactic 1
      case 3: // Tactic 2
      case 4: // Tactic 3
        currentTactic = command - 1;
        // Flash to confirm
        setLED(COLOR_ORANGE);
        delay(100);
        break;
      case 12: // Power/Start-Stop toggle
        if (running) {
          stopRobot();
        } else {
          running = true;
        }
        break;
    }
  }
}

// ==================== OLED Display ====================
#ifdef USE_DISPLAY
void updateDisplay() {
  oled.clear();

  bool fr = statusFR();
  bool fl = statusFL();
  bool r = statusR();
  bool l = statusL();
  int lineRVal = analogRead(SEN_Line_R);
  int lineLVal = analogRead(SEN_Line_L);

  // Row 0: Sensor rectangles
  drawSensorRect(0, 0, fl);    // Front-Left
  drawSensorRect(34, 0, fr);   // Front-Right
  drawSensorRect(68, 0, l);    // Side-Left
  drawSensorRect(102, 0, r);   // Side-Right

  // Row 2: Line sensor values
  oled.setCursor(0, 2);
  oled.print("L:");
  oled.print(lineLVal);
  oled.print(" R:");
  oled.print(lineRVal);

  // Row 3: Tactic and state
  oled.setCursor(0, 3);
  oled.print("T:");
  oled.print(currentTactic);
  oled.print(running ? " RUN" : " STOP");

  // IR command
  oled.setCursor(70, 3);
  oled.print(lastIRCommand);

  oled.update();
}

void drawSensorRect(int x, int y, bool filled) {
  if (filled) {
    oled.rect(x, y, x + 30, y + 7, OLED_FILL);
  } else {
    oled.rect(x, y, x + 30, y + 7, OLED_STROKE);
  }
}
#endif

// ==================== Setup ====================
void setup() {
#ifdef DEBUG_ENABLE
  Serial.begin(115200);
#endif

  // Motor pins
  pinMode(AIN_1, OUTPUT);
  pinMode(AIN_2, OUTPUT);
  pinMode(BIN_1, OUTPUT);
  pinMode(BIN_2, OUTPUT);

  // Opponent sensor pins (active-low, need pullup)
  pinMode(SEN_FR, INPUT);
  pinMode(SEN_FL, INPUT);
  pinMode(SEN_R, INPUT);
  pinMode(SEN_L, INPUT);

  // Button setup
  butt1.setDebounce(50);
  butt1.setTimeout(300);
  butt1.setClickTimeout(600);
  butt1.setType(HIGH_PULL);
  butt1.setDirection(NORM_OPEN);

  // NeoPixel
  pixels.begin();
  pixels.setBrightness(50);
  setLED(COLOR_WHITE);

  // Servo
  plow.attach(SERVO_PIN);
  plow.write(90); // neutral position

  // OLED
#ifdef USE_DISPLAY
  oled.init();
  oled.clear();
  oled.setScale(1);
  oled.home();
  oled.print("Joltik V2 Ready");
  oled.update();
#endif

  // Stop motors
  drive(0, 0);

  // ---- Wait for start (button press) ----
  setLED(COLOR_WHITE);

#ifdef DEBUG_ENABLE
  Serial.println("Waiting for start...");
#endif

  bool started = false;
  while (!started) {
    butt1.tick();

    // Single click to start
    if (butt1.isSingle()) {
      started = true;
      break;
    }

    // Double click to cycle tactics while waiting
    if (butt1.isDouble()) {
      currentTactic = (currentTactic + 1) % TACTIC_COUNT;
#ifdef DEBUG_ENABLE
      Serial.print("Tactic selected: ");
      Serial.println(currentTactic);
#endif
      // Flash tactic number
      for (uint8_t i = 0; i <= currentTactic; i++) {
        setLED(COLOR_YELLOW);
        delay(150);
        setLED(COLOR_OFF);
        delay(150);
      }
      setLED(COLOR_WHITE);
    }

#ifdef USE_DISPLAY
    updateDisplay();
#endif

#ifdef DEBUG_ENABLE
    // Print sensor debug info periodically
    static uint32_t lastDebug = 0;
    if (millis() - lastDebug > 500) {
      lastDebug = millis();
      Serial.print("FL:");
      Serial.print(statusFL());
      Serial.print(" FR:");
      Serial.print(statusFR());
      Serial.print(" L:");
      Serial.print(statusL());
      Serial.print(" R:");
      Serial.print(statusR());
      Serial.print(" LineL:");
      Serial.print(analogRead(SEN_Line_L));
      Serial.print(" LineR:");
      Serial.print(analogRead(SEN_Line_R));
      Serial.print(" Tactic:");
      Serial.println(currentTactic);
    }
#endif
  }

  // Start!
  running = true;
  setLED(COLOR_GREEN);

  // 5-second countdown (competition rules)
  for (int i = 5; i > 0; i--) {
#ifdef DEBUG_ENABLE
    Serial.println(i);
#endif
#ifdef USE_DISPLAY
    oled.clear();
    oled.setScale(3);
    oled.setCursor(50, 0);
    oled.print(i);
    oled.update();
#endif
    setLED(i % 2 ? COLOR_GREEN : COLOR_OFF);
    delay(1000);
  }
  setLED(COLOR_GREEN);

#ifdef USE_DISPLAY
  oled.clear();
  oled.setScale(1);
  oled.home();
  oled.print("GO!");
  oled.update();
#endif

  // Execute selected tactic start routine
  tactics(currentTactic);
}

// ==================== Main Loop ====================
void loop() {
  butt1.tick();

  // Button press stops the robot
  if (butt1.isSingle()) {
    stopRobot();
    // When stopRobot returns, we were restarted
    tactics(currentTactic);
    return;
  }

  // Check line sensors (always active)
  bool lineL = lineSensL();
  bool lineR = lineSensR();

  if (!lineL && !lineR) {
    backoff(RIGHT);
    return;
  }
  if (!lineL) {
    // Left edge - back off turning right
    backoff(RIGHT);
    return;
  }
  if (!lineR) {
    // Right edge - back off turning left
    backoff(LEFT);
    return;
  }

  // No opponent detected - search
  if (!opponentDetected()) {
    search();
    count = 0;
#ifdef DEBUG_ENABLE
    Serial.println("Searching");
#endif
  }
  // Opponent detected - attack
  else {
    attack();
#ifdef DEBUG_ENABLE
    Serial.println("Attacking");
#endif
  }

#ifdef USE_DISPLAY
  static uint32_t lastDisplayUpdate = 0;
  if (millis() - lastDisplayUpdate > 100) {
    lastDisplayUpdate = millis();
    updateDisplay();
  }
#endif
}

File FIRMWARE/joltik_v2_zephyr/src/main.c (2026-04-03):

/*
 * Joltik V2 Mini Sumo Competition Firmware - Zephyr RTOS
 *
 * State machine: WAITING -> countdown -> tactics -> combat loop
 * IR remote handled in dedicated thread via k_msgq.
 */

#include <zephyr/kernel.h>
#include <zephyr/logging/log.h>
#include <zephyr/sys/atomic.h>

#include "motors.h"
#include "sensors.h"
#include "led.h"
#include "servo.h"
#include "combat.h"
#include "tactics.h"
#include "button.h"
#include "rc5.h"
#include "settings.h"

LOG_MODULE_REGISTER(main, LOG_LEVEL_INF);

/* Shared state between main thread, IR thread, and button */
static atomic_t running = ATOMIC_INIT(0);
static atomic_t current_tactic = ATOMIC_INIT(0);
static K_EVENT_DEFINE(start_event);

#define EVENT_START BIT(0)

/* ==================== IR Thread ==================== */
#define IR_STACK_SIZE 1024
#define IR_PRIORITY   5

static void ir_thread_entry(void *p1, void *p2, void *p3)
{
	ARG_UNUSED(p1);
	ARG_UNUSED(p2);
	ARG_UNUSED(p3);

	struct rc5_message msg;

	LOG_INF("IR thread started");

	while (1) {
		if (!rc5_get_message(&msg, -1)) {
			continue;
		}

		LOG_INF("IR: addr=%u cmd=%u toggle=%u",
			msg.address, msg.command, msg.toggle);

		switch (msg.command) {
		case RC5_CMD_TACTIC_1:
		case RC5_CMD_TACTIC_2:
		case RC5_CMD_TACTIC_3:
		case RC5_CMD_TACTIC_4:
			atomic_set(&current_tactic, msg.command - 1);
			led_set_state(STATE_TACTIC_SELECT);
			k_msleep(100);
			break;

		case RC5_CMD_POWER:
			if (atomic_get(&running)) {
				atomic_set(&running, 0);
				motors_stop();
			} else {
				k_event_post(&start_event, EVENT_START);
			}
			break;
		}
	}
}

K_THREAD_DEFINE(ir_tid, IR_STACK_SIZE, ir_thread_entry,
		NULL, NULL, NULL, IR_PRIORITY, 0, 0);

/* ==================== Stop & Tactic Select ==================== */
static void stop_robot(void)
{
	atomic_set(&running, 0);
	motors_stop();
	combat_reset_count();
	LOG_INF("STOPPED");

	/* Blink white, wait for restart */
	while (!atomic_get(&running)) {
		enum button_event evt = button_poll();

		if (evt == BTN_SINGLE) {
			break;
		}
		if (evt == BTN_DOUBLE) {
			uint8_t t = (atomic_get(&current_tactic) + 1) % TACTIC_COUNT;
			atomic_set(&current_tactic, t);
			g_settings.current_tactic = t;
			LOG_INF("Tactic: %u", t);

			for (uint8_t i = 0; i <= t; i++) {
				led_set_state(STATE_TACTIC_SELECT);
				k_msleep(150);
				led_off();
				k_msleep(150);
			}
			continue;
		}

		/* Check for IR-triggered start */
		if (k_event_wait(&start_event, EVENT_START, false, K_NO_WAIT)) {
			k_event_clear(&start_event, EVENT_START);
			break;
		}

		led_set_state(STATE_WAITING);
		k_msleep(500);
		led_off();
		k_msleep(500);
	}

	atomic_set(&running, 1);
}

/* ==================== Main ==================== */
int main(void)
{
	int ret;

	LOG_INF("Joltik V2 Mini Sumo - Zephyr RTOS");

	/* Initialize all subsystems */
	ret = motors_init();
	if (ret) {
		LOG_ERR("Motors init failed: %d", ret);
	}

	ret = sensors_init();
	if (ret) {
		LOG_ERR("Sensors init failed: %d", ret);
	}

	ret = led_init();
	if (ret) {
		LOG_ERR("LED init failed: %d", ret);
	}

	ret = servo_init();
	if (ret) {
		LOG_ERR("Servo init failed: %d", ret);
	}

	ret = button_init();
	if (ret) {
		LOG_ERR("Button init failed: %d", ret);
	}

	ret = rc5_init();
	if (ret) {
		LOG_ERR("RC5 init failed: %d", ret);
	}

	ret = app_settings_init();
	if (ret) {
		LOG_ERR("Settings init failed: %d", ret);
	}

	/* Apply loaded settings */
	atomic_set(&current_tactic, g_settings.current_tactic);

	motors_stop();
	led_set_state(STATE_WAITING);

	LOG_INF("Waiting for start...");

	/* ---- Wait for start (button or IR) ---- */
	bool started = false;
	while (!started) {
		enum button_event evt = button_poll();

		if (evt == BTN_SINGLE) {
			started = true;
			break;
		}
		if (evt == BTN_DOUBLE) {
			uint8_t t = (atomic_get(&current_tactic) + 1) % TACTIC_COUNT;
			atomic_set(&current_tactic, t);
			g_settings.current_tactic = t;
			LOG_INF("Tactic selected: %u", t);

			for (uint8_t i = 0; i <= t; i++) {
				led_set_state(STATE_TACTIC_SELECT);
				k_msleep(150);
				led_off();
				k_msleep(150);
			}
			led_set_state(STATE_WAITING);
			continue;
		}

		/* Check for IR-triggered start */
		if (k_event_wait(&start_event, EVENT_START, false, K_NO_WAIT)) {
			k_event_clear(&start_event, EVENT_START);
			started = true;
			break;
		}

		k_msleep(50);
	}

	/* ---- 5-second countdown ---- */
	atomic_set(&running, 1);
	led_set_state(STATE_COUNTDOWN);

	for (int i = 5; i > 0; i--) {
		LOG_INF("Countdown: %d", i);
		if (i % 2) {
			led_set_state(STATE_COUNTDOWN);
		} else {
			led_off();
		}
		k_msleep(1000);
	}
	led_set_state(STATE_SEARCHING);

	/* Execute selected tactic start routine */
	uint8_t tactic = atomic_get(&current_tactic);
	tactics_execute(tactic);

	/* ---- Main combat loop ---- */
	LOG_INF("Combat loop started");

	while (1) {
		/* Button press stops the robot */
		enum button_event evt = button_poll();
		if (evt == BTN_SINGLE) {
			stop_robot();
			/* Restart with tactics */
			tactic = atomic_get(&current_tactic);
			/* 5-second countdown before restart */
			for (int i = 5; i > 0; i--) {
				LOG_INF("Countdown: %d", i);
				if (i % 2) {
					led_set_state(STATE_COUNTDOWN);
				} else {
					led_off();
				}
				k_msleep(1000);
			}
			tactics_execute(tactic);
			continue;
		}

		/* IR-triggered stop */
		if (!atomic_get(&running)) {
			stop_robot();
			tactic = atomic_get(&current_tactic);
			for (int i = 5; i > 0; i--) {
				LOG_INF("Countdown: %d", i);
				if (i % 2) {
					led_set_state(STATE_COUNTDOWN);
				} else {
					led_off();
				}
				k_msleep(1000);
			}
			tactics_execute(tactic);
			continue;
		}

		/* Check line sensors (always active) */
		bool line_l = line_on_ring_left();
		bool line_r = line_on_ring_right();

		if (!line_l && !line_r) {
			backoff(DIR_RIGHT);
			continue;
		}
		if (!line_l) {
			backoff(DIR_RIGHT);
			continue;
		}
		if (!line_r) {
			backoff(DIR_LEFT);
			continue;
		}

		/* No opponent - search; opponent - attack */
		if (!opponent_detected()) {
			search();
			combat_reset_count();
			LOG_DBG("Searching");
		} else {
			attack();
			LOG_DBG("Attacking");
		}
	}

	return 0;
}

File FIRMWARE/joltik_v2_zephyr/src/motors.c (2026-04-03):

#include <zephyr/kernel.h>
#include <zephyr/drivers/pwm.h>
#include <zephyr/drivers/gpio.h>
#include <zephyr/logging/log.h>
#include <stdlib.h>

#include "motors.h"

LOG_MODULE_REGISTER(motors, LOG_LEVEL_INF);

#define ZEPHYR_USER_NODE DT_PATH(zephyr_user)

static const struct pwm_dt_spec motor_left_pwm =
	PWM_DT_SPEC_GET(DT_NODELABEL(motor_l));
static const struct pwm_dt_spec motor_right_pwm =
	PWM_DT_SPEC_GET(DT_NODELABEL(motor_r));

static const struct gpio_dt_spec motor_left_dir =
	GPIO_DT_SPEC_GET(ZEPHYR_USER_NODE, motor_left_dir_gpios);
static const struct gpio_dt_spec motor_right_dir =
	GPIO_DT_SPEC_GET(ZEPHYR_USER_NODE, motor_right_dir_gpios);

int motors_init(void)
{
	int ret;

	if (!pwm_is_ready_dt(&motor_left_pwm) ||
	    !pwm_is_ready_dt(&motor_right_pwm)) {
		LOG_ERR("PWM devices not ready");
		return -ENODEV;
	}

	if (!gpio_is_ready_dt(&motor_left_dir) ||
	    !gpio_is_ready_dt(&motor_right_dir)) {
		LOG_ERR("Motor direction GPIO not ready");
		return -ENODEV;
	}

	ret = gpio_pin_configure_dt(&motor_left_dir, GPIO_OUTPUT_INACTIVE);
	if (ret < 0) {
		return ret;
	}

	ret = gpio_pin_configure_dt(&motor_right_dir, GPIO_OUTPUT_INACTIVE);
	if (ret < 0) {
		return ret;
	}

	motors_stop();
	LOG_INF("Motors initialized");
	return 0;
}

void drive(int left, int right)
{
	left = CLAMP(left, -255, 255);
	right = CLAMP(right, -255, 255);

	/* Left motor: direction + PWM duty */
	gpio_pin_set_dt(&motor_left_dir, left < 0 ? 1 : 0);
	uint32_t left_pulse = (motor_left_pwm.period * (uint32_t)abs(left)) / 255;
	pwm_set_pulse_dt(&motor_left_pwm, left_pulse);

	/* Right motor: direction + PWM duty */
	gpio_pin_set_dt(&motor_right_dir, right < 0 ? 1 : 0);
	uint32_t right_pulse = (motor_right_pwm.period * (uint32_t)abs(right)) / 255;
	pwm_set_pulse_dt(&motor_right_pwm, right_pulse);
}

void motors_stop(void)
{
	drive(0, 0);
}

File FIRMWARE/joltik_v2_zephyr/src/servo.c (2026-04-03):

#include <zephyr/kernel.h>
#include <zephyr/drivers/pwm.h>
#include <zephyr/logging/log.h>

#include "servo.h"

LOG_MODULE_REGISTER(servo, LOG_LEVEL_INF);

static const struct pwm_dt_spec servo_pwm =
	PWM_DT_SPEC_GET(DT_NODELABEL(servo_ch));

/* Standard servo pulse range: 500us (0 deg) to 2500us (180 deg) */
#define SERVO_MIN_PULSE_US  500
#define SERVO_MAX_PULSE_US  2500

int servo_init(void)
{
	if (!pwm_is_ready_dt(&servo_pwm)) {
		LOG_ERR("Servo PWM not ready");
		return -ENODEV;
	}

	servo_set_angle(90);
	LOG_INF("Servo initialized (90 deg)");
	return 0;
}

void servo_set_angle(uint8_t angle)
{
	if (angle > 180) {
		angle = 180;
	}

	uint32_t pulse_us = SERVO_MIN_PULSE_US +
		((uint32_t)angle * (SERVO_MAX_PULSE_US - SERVO_MIN_PULSE_US)) / 180;

	pwm_set_pulse_dt(&servo_pwm, PWM_USEC(pulse_us));
}

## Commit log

2026-03-14 Add SolidWorks CAD designs and DXF cut files for robot chassis
    [Assem_Power_port.SLDASM, Base plate.SLDPRT, Base plate_3mm.DXF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]
2026-03-14 Add vendored Arduino libraries (NeoPixel, GyverMotor, RC5, SharpIR)
2026-03-14 Add V1 competition firmware for ATmega328 (Arduino Nano)
2026-03-14 Add V2 board test firmware for RP2040-Zero
2026-03-14 Add V2 competition firmware ported to RP2040-Zero
    Port V1 competition logic to V2 board with:
    - 4 digital opponent sensors (replacing SharpIR analog)
    - Dual analog line sensors (always active)
    - WS2812 RGB LED with color-coded states
    - RC5 IR remote on second core
    - Servo support, optional OLED display
    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
2026-03-14 Add README with project overview, build instructions, and V2 pin mapping
2026-03-16 Add JoltikV2 test firmware for RP2040-Zero
    Implement core functionality for the JoltikV2 robot, including motor control, sensor integration, and remote command handling. Features include:
    - Support for GyverMotor and button-based start
    - Line and opponent detection with state management
    - Debugging output and EEPROM settings management
    - RGB LED status indication
    This firmware serves as a foundation for further development and testing of the robot's capabilities.
2026-04-03 Port V2 competition firmware to Zephyr RTOS
    Full port of JoltikV2_sumo_firmware from Arduino to Zephyr 4.3 for
    RP2040-Zero with maximum RTOS feature utilization:
    - Devicetree overlay for all pin mappings (PWM, GPIO, ADC, PIO)
    - Zephyr Shell over USB CDC ACM for runtime debug and tuning
    - Zephyr Logging replacing #ifdef DEBUG_ENABLE
    - NVS Settings subsystem for persistent storage of tactic, thresholds,
    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
2026-04-03 Add .gitignore and update LICENSE with current copyright
    - Introduced a .gitignore file to exclude build artifacts and OS/editor junk.
    - Updated LICENSE file to reflect the current copyright holder as Danila Surok (2026).
2026-04-03 Add unit tests for Zephyr firmware (59 pass, 7 suites)
    Ztest-based tests running on native_sim with emulated hardware:
    - combat: 13 tests — attack priorities, backoff, search, edge detection
    - led_tests: 9 tests — state-to-color mapping, custom colors, off
    - motors: 8 tests — drive direction, clamping, forward/reverse/stop
    - rc5_decode: 10 tests — timing boundaries, state machine, reset
    - sensors: 13 tests (3 skip) — opponent GPIO, line ADC, threshold
    - servo: 6 tests — angle conversion, clamping, sweep
    - settings_tests: 3 tests — defaults, NVS save/reload
    Infrastructure: fake LED strip driver, native_sim DT overlay with
    gpio_emul + fake-pwm + adc_emul. Run with `make test`.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
    [main.c, rc5.c]
2026-04-03 Rename V1 firmware sketch and add CI workflow
    Rename Sumo_last_test_firmware.ino to JoltikV1_last_test_firmware.ino
    to match the directory name. Add GitHub Actions CI that compiles all
    Arduino sketches (AVR, RP2040, ESP8266) and builds Zephyr firmware.
2026-04-03 Add Zephyr firmware README and docs
    README with quick start, build targets, and project structure.
    Docs cover architecture (state machine, threads, attack priority),
    pinout, shell commands, NVS settings, and unit testing.
